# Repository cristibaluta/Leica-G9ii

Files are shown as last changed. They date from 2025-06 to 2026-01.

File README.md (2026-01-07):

# Leica G9II

> The internals of a Panasonic Lumix G9II inside a Leica M-style body — featuring custom CNC-machined parts and redesigned flex cables and buttons.

---

## 📸 Overview

This project is an attempt to make a beautiful small camera from a Lumix G9II body. The camera is focused on street photography and has missing buttons and features.

If you are an expert in any relevant field and see mistakes you are welcome to open issues for discussion, my only qualification to do this is that I was into electronics a long time ago.

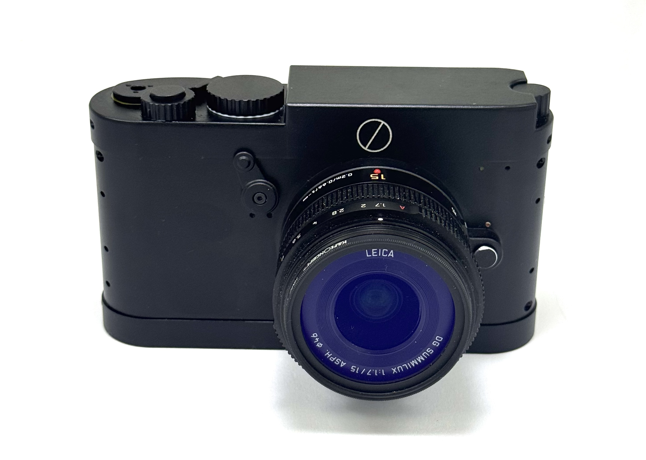
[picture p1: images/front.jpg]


---

## What's Included

- `/CADs/` – STEP files for CNC machining, including threads sheets
- `/FPCBs/` – Schematics and gerber files for the flex cables
- `/Datasheets/` – Some datasheets from used components
- `/BOM/` – List of extra items and purchase links

---

## Materials (BOM)

| Part | Description | Notes |
|---|---|---|
| Top plate | Milled aluminum | Included in CADs |
| Base plate | Milled aluminum |  |
| Front | Milled aluminum |  |
| Back | Milled aluminum |  |
| Heatsink | Milled copper |  |
| Flex cable | Internal routing rework | Included in FPCBs |
| Screws | M1.6 and M2 | Refer to threads sheets in CADs |
| Body (G9II) | Donor camera ||

---

## Build Instructions

> ⚠️ Advanced DIY skills required: electronics, soldering, disassembly without breaking, modifying original parts
> ⚠️ WIP

1. Disassemble Lumix G9II (see [https://www.youtube.com/@CameraSurgery])
2. Machine or print parts from `/CADs/`
3. Print flex cables from `/FPCBs/`
4. Install mount, lens release button
5. Install shutter
6. Install sensor
7. Install front lever and battery flex cable
8. Install heatsink
9. Install mainboard
10. Install top plate dials and flex cables
11. Install back buttons and flex cable
12. Install screen
13. Install viewfinder
14. Install wifi module
15. Assemble
16. Add leatherete
17. Install front lever

---

## Parts removed

1. Lens release push detector (not sure what it was doing beside displaying some info on the screen). There is not enough space to add this push detector
2. The following buttons: ISO-WB, front custom buttons

---

## TO DO:
- The dials are too lose
- The buttons are too short
- Thread missing from the lever clicker
- Remove back wheel
- Dials gaskets too thin (0.5mm), must be wider (1mm)
- Front and back could be extended up and down for better strength

---

## Licence

This project is licensed under the CERN Open Hardware Licence Version 2 – Permissive (CERN-OHL-P-2.0).

---

## 💬 Credits

Created by [Cristian Baluta]  
Youtube: [https://www.youtube.com/@CameraSurgery]

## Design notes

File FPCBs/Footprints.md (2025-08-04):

# Footprints

> 

- HTK AXA573062P https://4donline.ihs.com/images/VipMasterIC/IC/HOND/HOND-S-A0017916280/HOND-S-A0017916306-1.pdf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

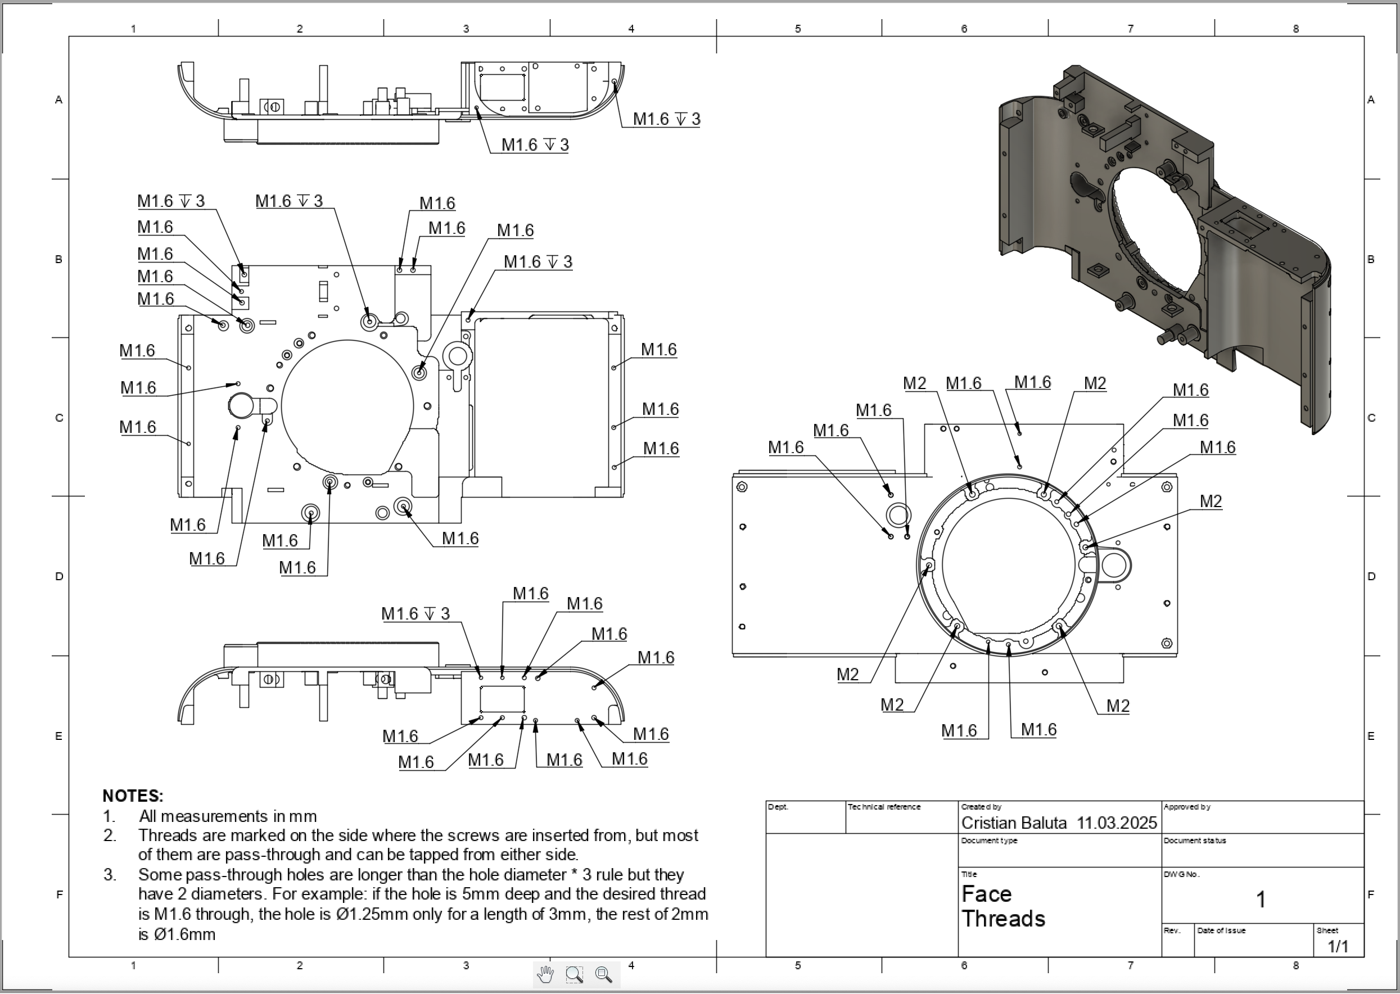
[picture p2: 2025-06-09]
CADs/Face-Threads.png

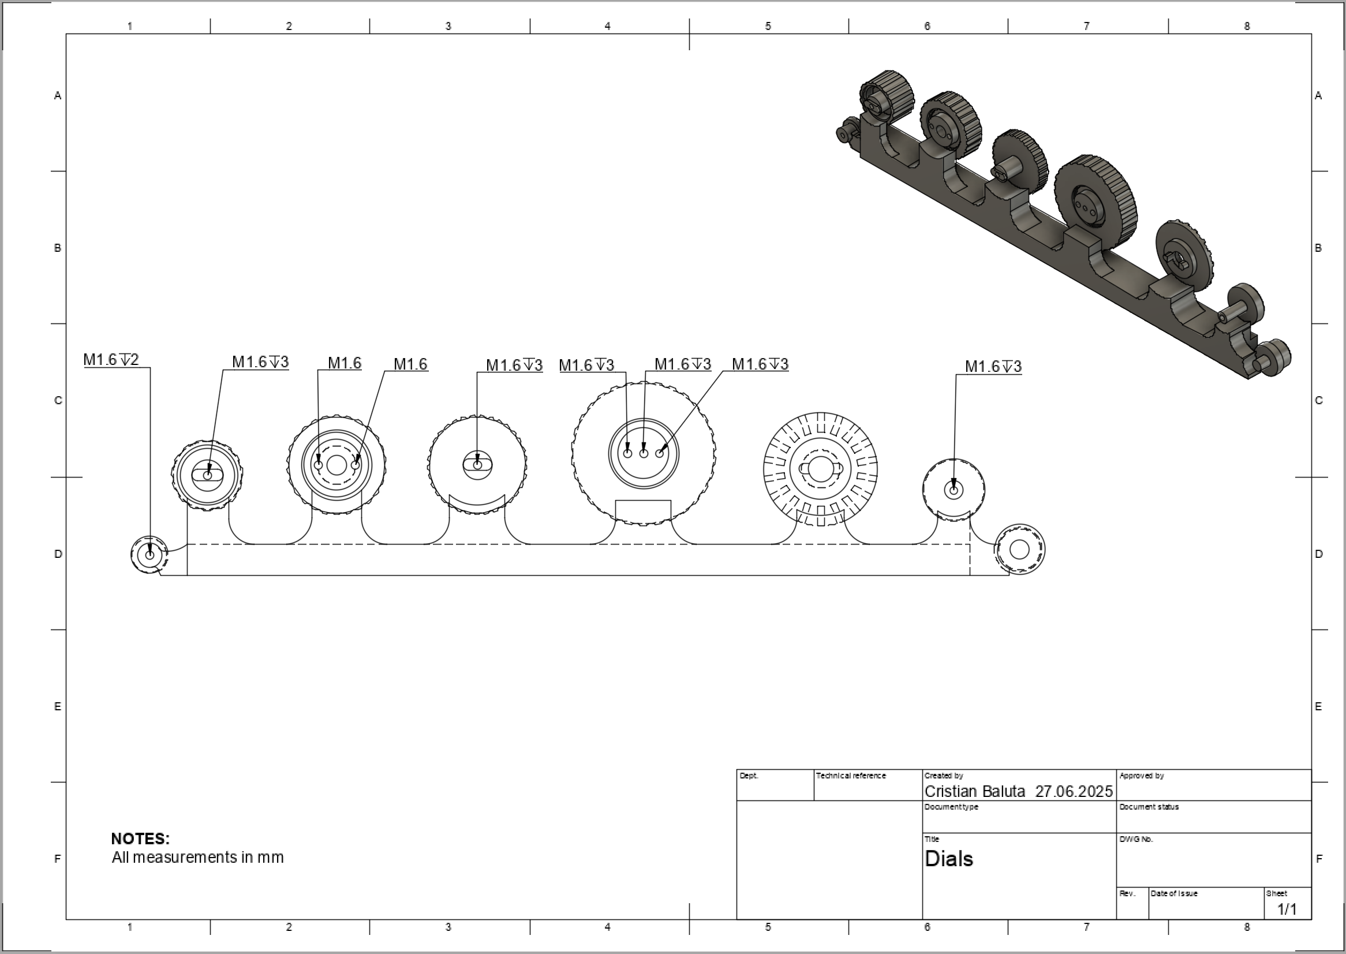
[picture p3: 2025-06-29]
CADs/Dials/Dials-Threads.png

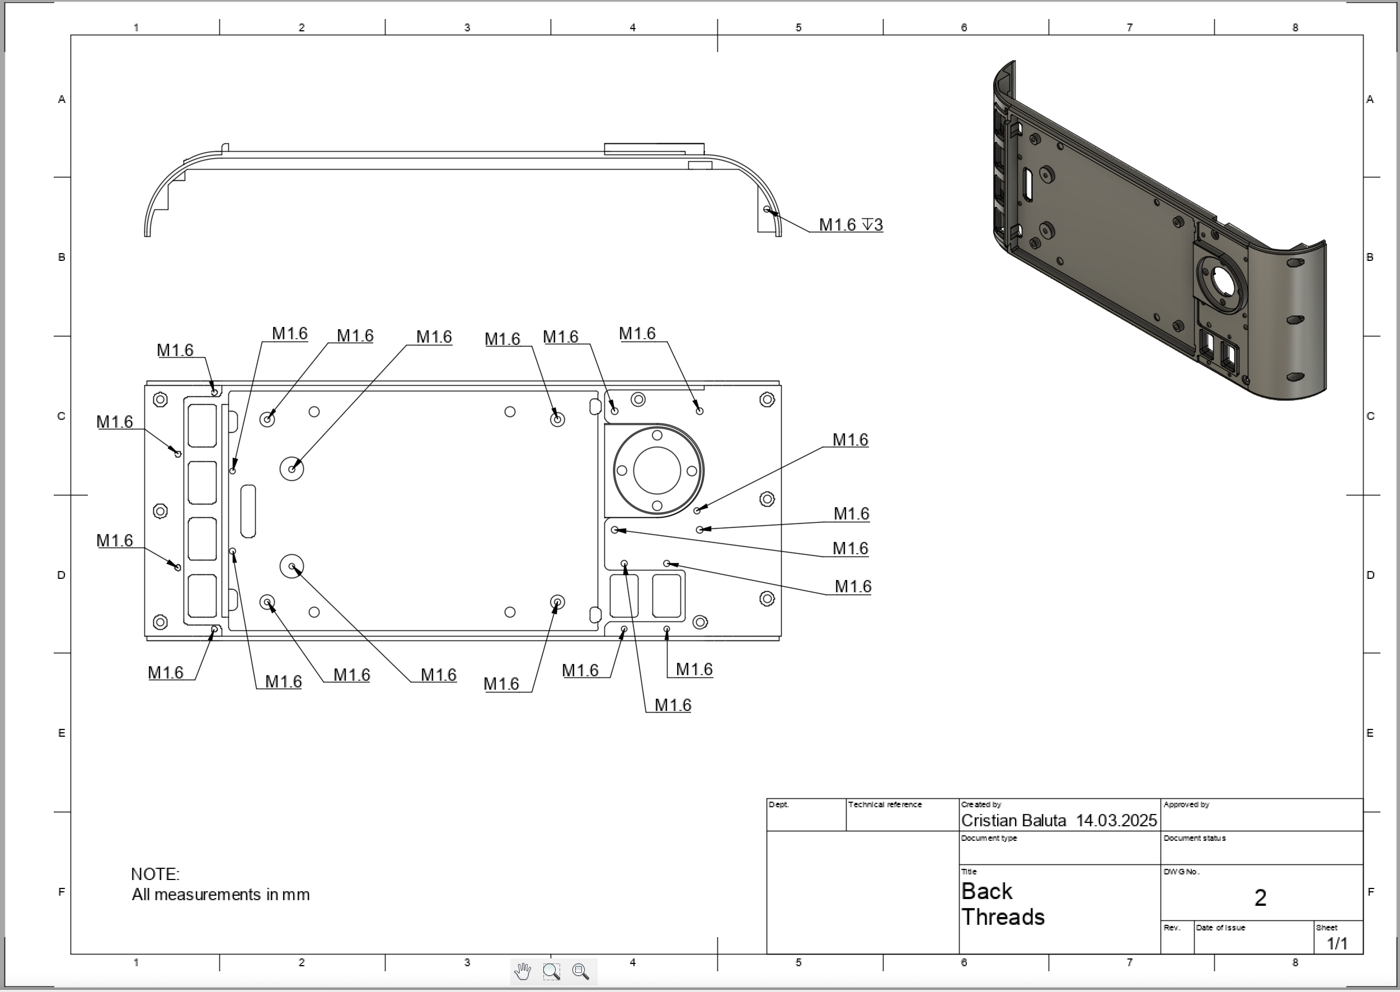
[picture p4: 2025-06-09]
CADs/Back-Threads.png

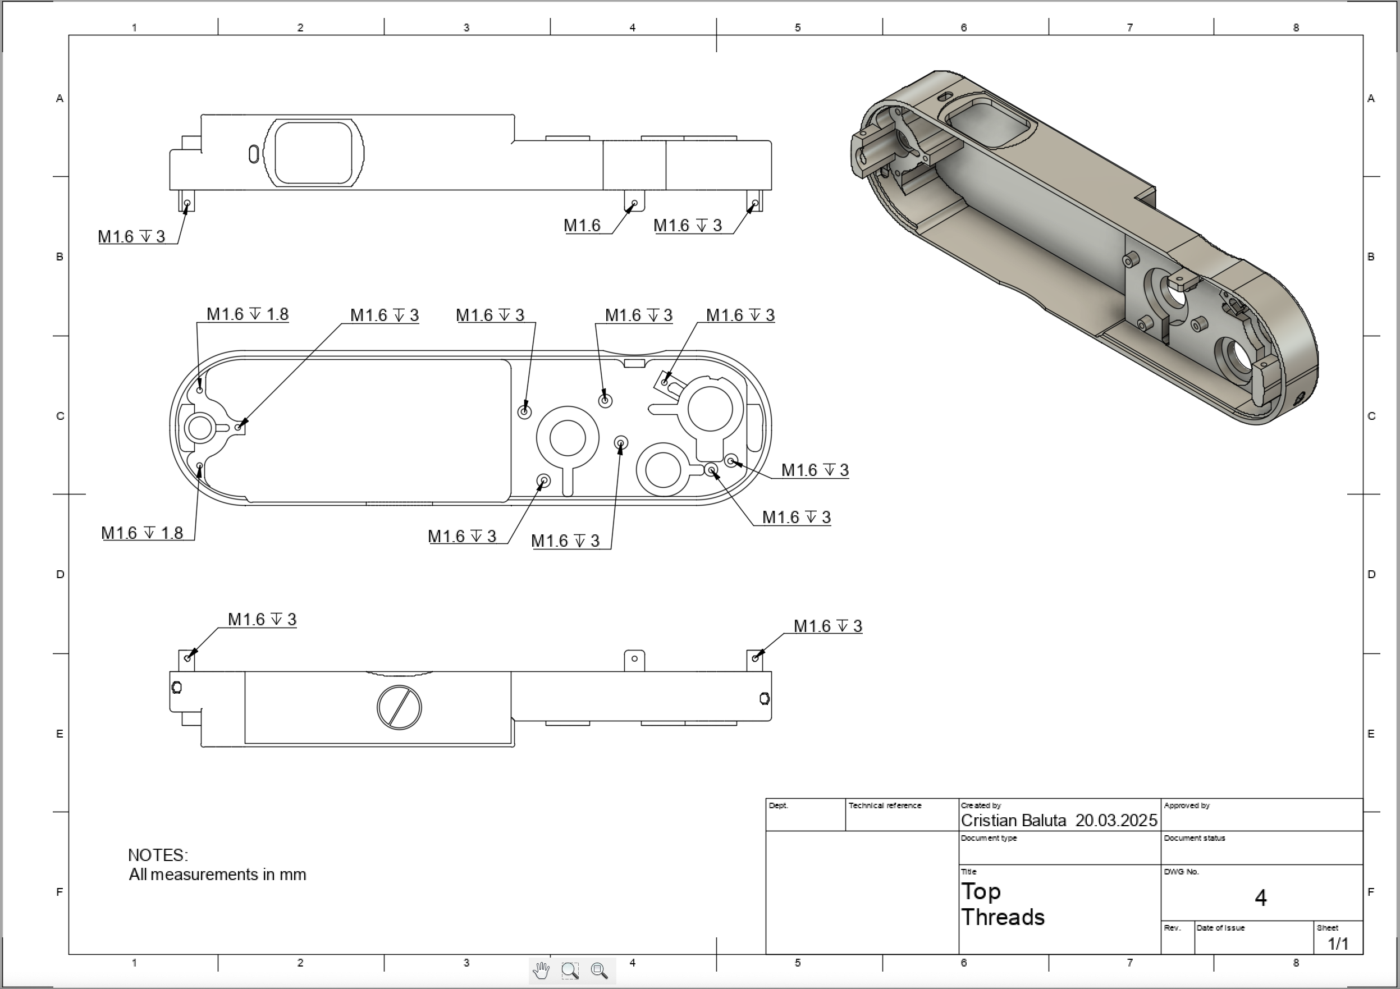
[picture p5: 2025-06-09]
CADs/Top-Threads.png

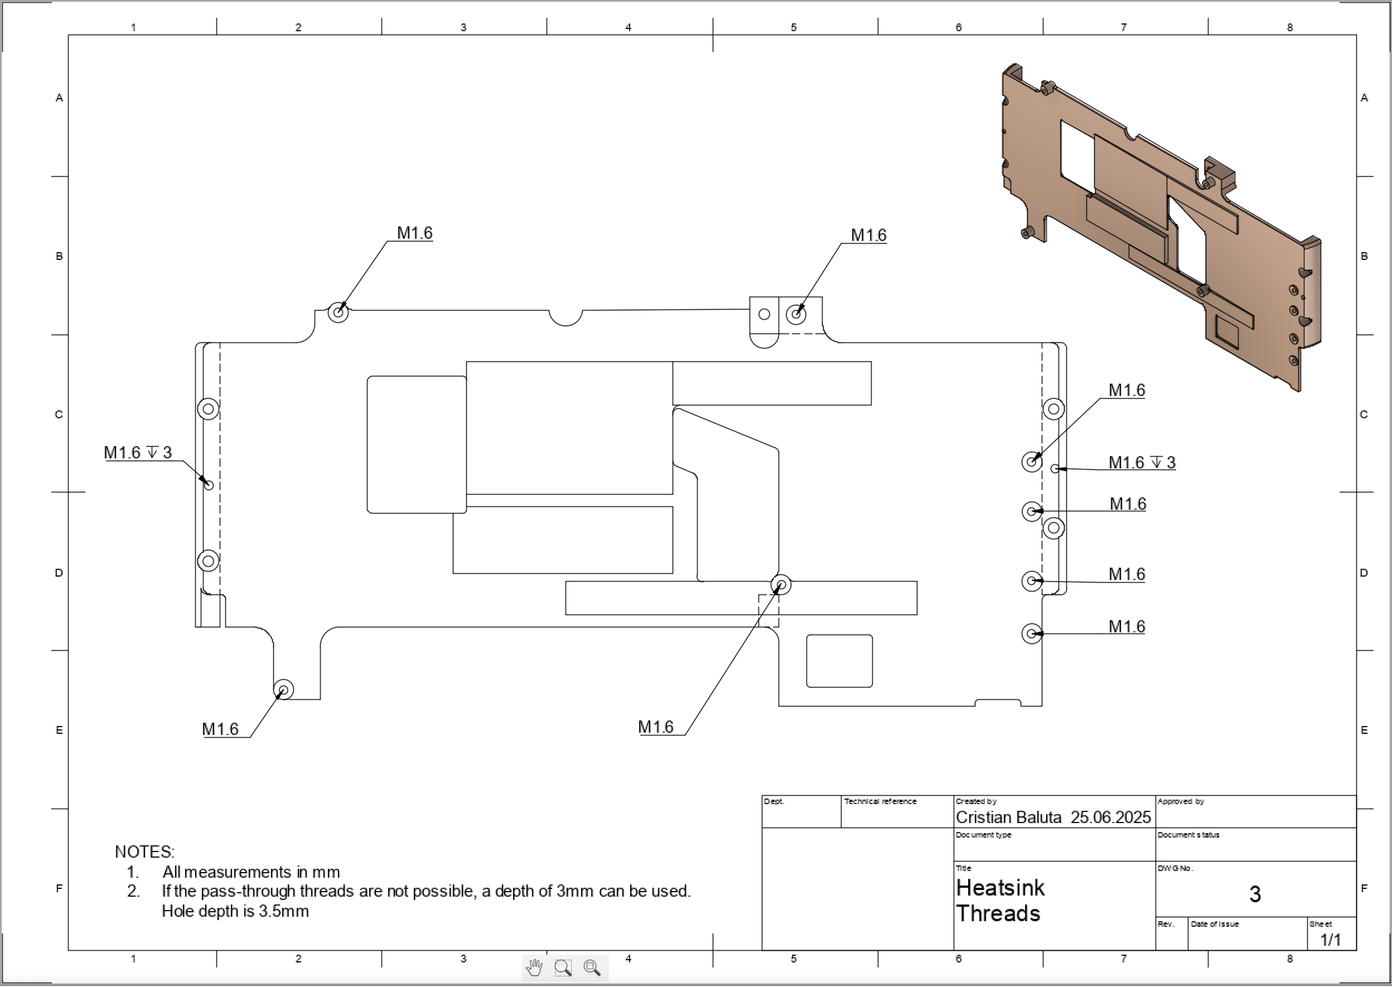
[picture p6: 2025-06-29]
CADs/Heatsink-Threads.png

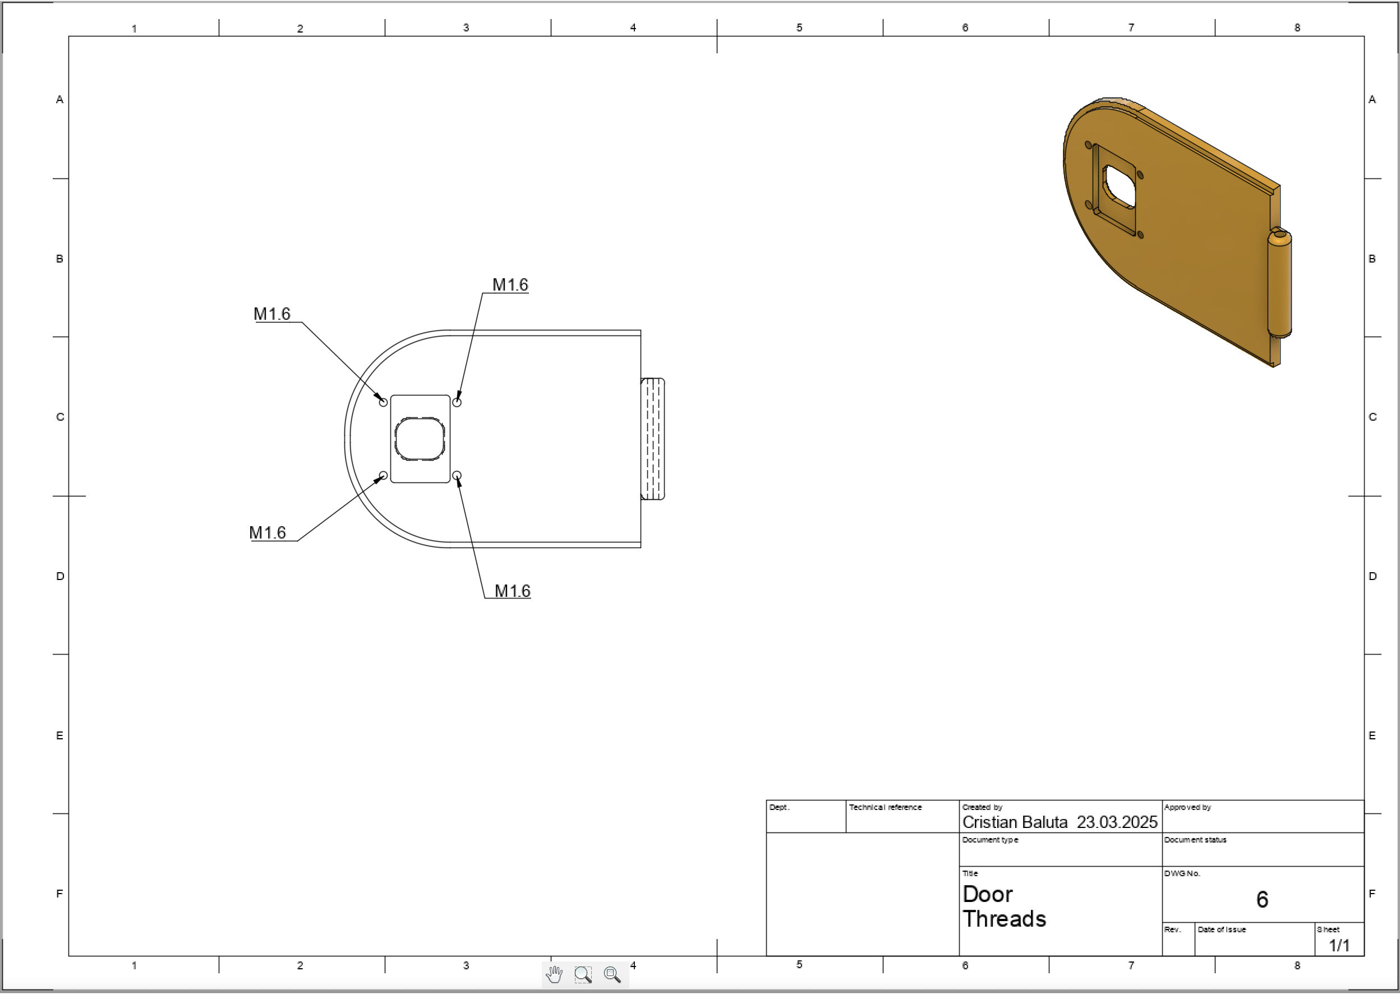
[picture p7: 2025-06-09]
CADs/Door-Threads.png

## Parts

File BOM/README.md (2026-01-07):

# BOM

## Screws

- M1.6 for closing the case. Effective diameter of this screws are 1.57mm, be careful some are poorer quality and smaller diameter. https://www.aliexpress.com/item/4001248931159.html
- M2 for the front lever

## Components

- 0603 resistors replacing the original which were too tiny https://www.aliexpress.com/item/1005008650089395.html
- FPC 61 pins, 2 rows, 0.2 pitch for the EVF extender https://www.aliexpress.com/item/1005001817777187.html
- Canon shutter release button https://www.aliexpress.com/item/1005007803697458.html
- Olympus shutter release button for the second shutter

## Miscellaneous

- Grease https://www.aliexpress.com/item/1005006057635782.html

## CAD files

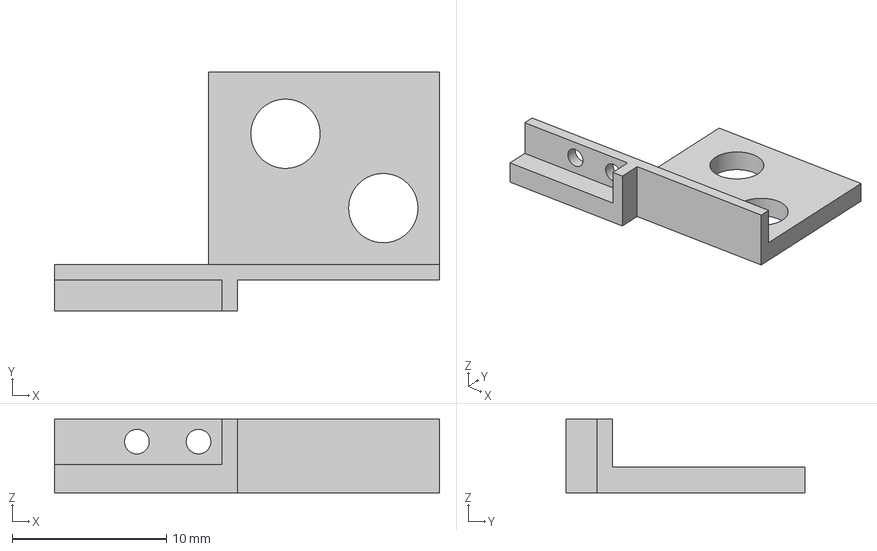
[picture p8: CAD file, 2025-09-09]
CADs/Dials/Gyro.step
25.0 x 15.5 x 4.80 mm

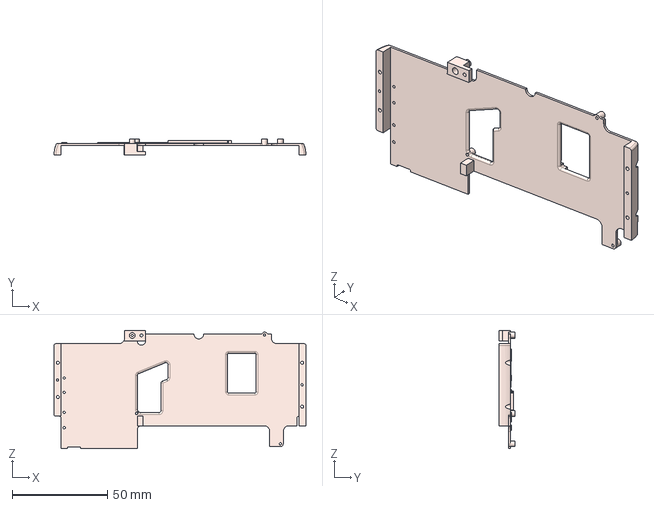
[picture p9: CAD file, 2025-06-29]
CADs/Heatsink.step
132.0 x 8.50 x 62.0 mm

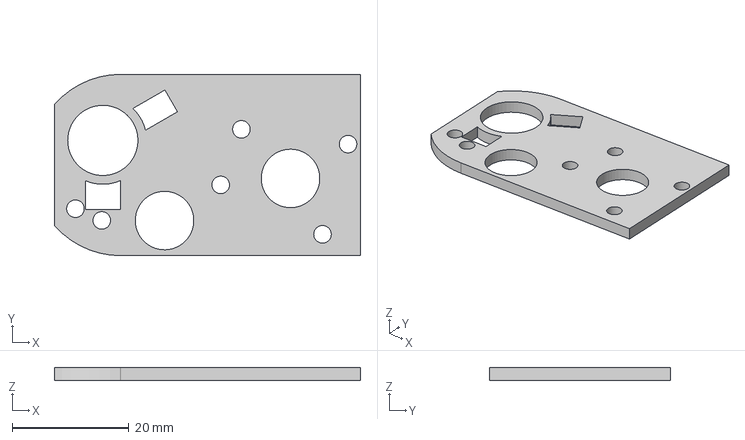
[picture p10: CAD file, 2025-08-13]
CADs/Dials/Mask.step
52.3 x 31.0 x 2.30 mm

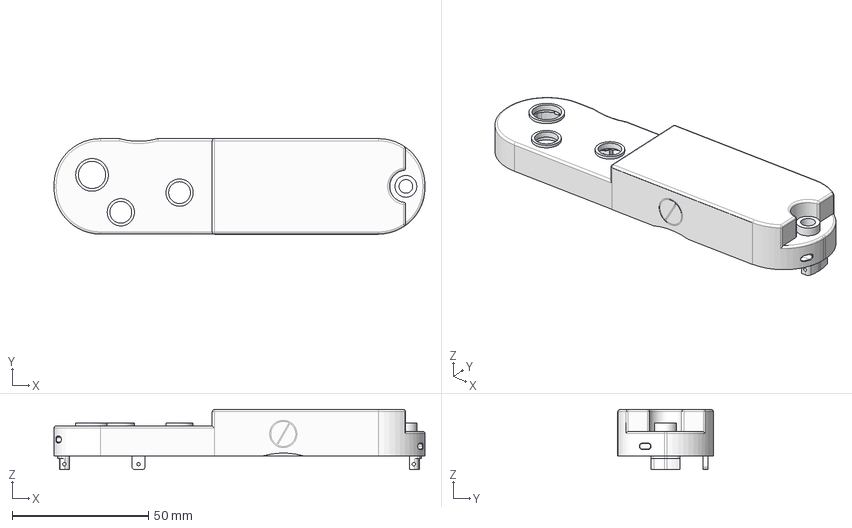
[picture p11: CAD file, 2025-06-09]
CADs/Top.step
136.0 x 35.1 x 22.0 mm

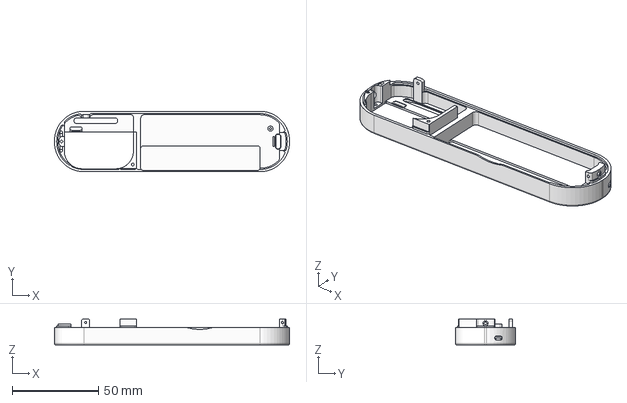
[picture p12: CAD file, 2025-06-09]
CADs/Base Plate.step
136.0 x 35.0 x 15.0 mm

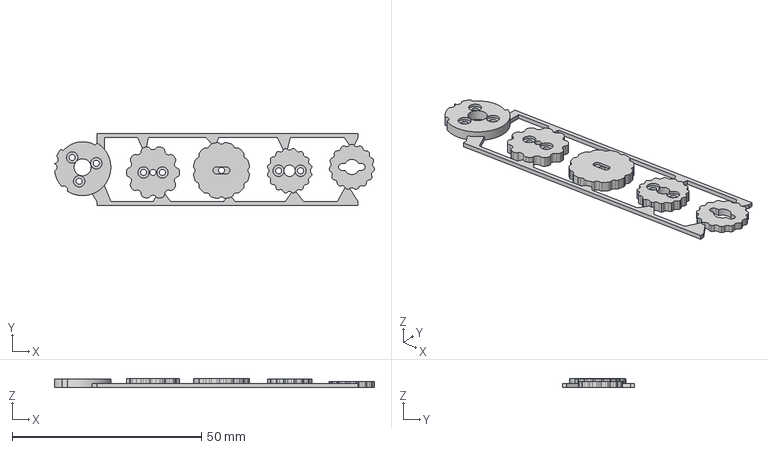
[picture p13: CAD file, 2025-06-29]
CADs/Dials/Clickers-connected.step
84.5 x 19.1 x 2.30 mm

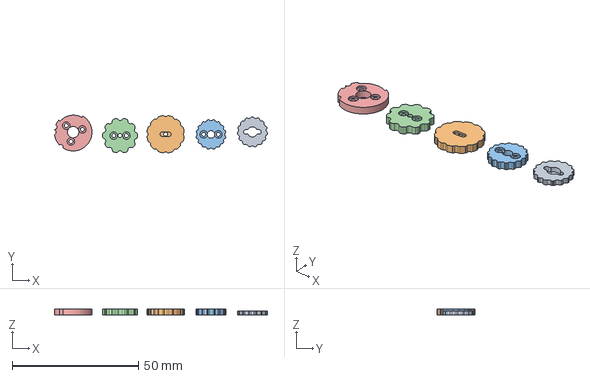
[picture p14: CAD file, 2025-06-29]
CADs/Dials/Clickers-separated.step
84.5 x 15.0 x 2.30 mm

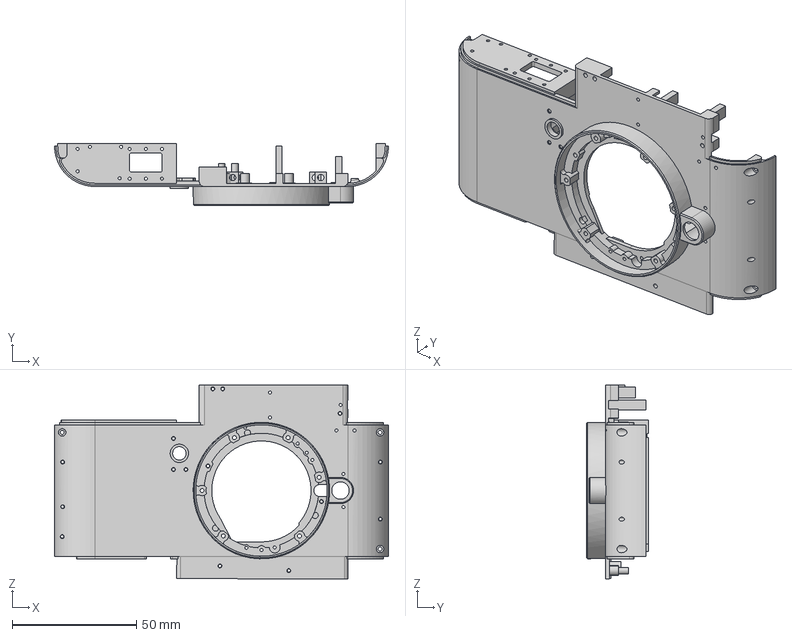
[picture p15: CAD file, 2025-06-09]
CADs/Face.step
134.6 x 24.9 x 78.0 mm

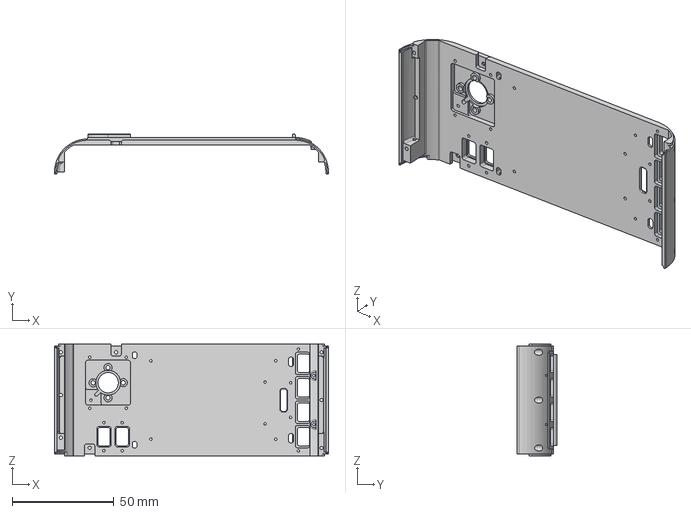
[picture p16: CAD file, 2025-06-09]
CADs/Back.step
134.6 x 19.8 x 55.0 mm

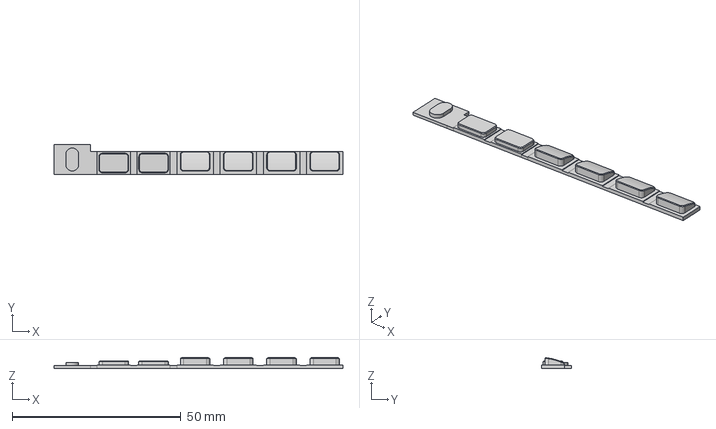
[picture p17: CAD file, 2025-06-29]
CADs/Dials/Back Buttons.step
85.6 x 8.88 x 3.17 mm

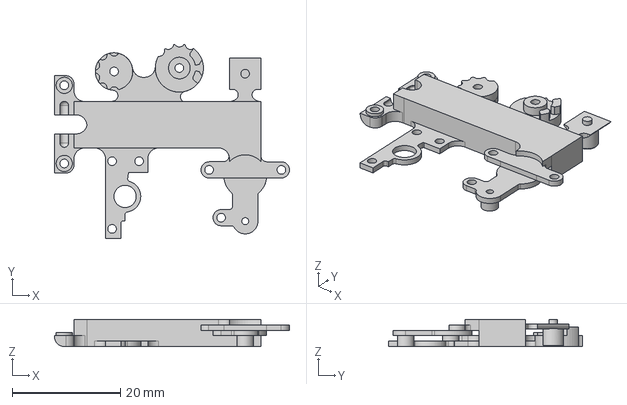
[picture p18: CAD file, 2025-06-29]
CADs/Dials/Miscellaneous.step
43.4 x 35.9 x 5.00 mm

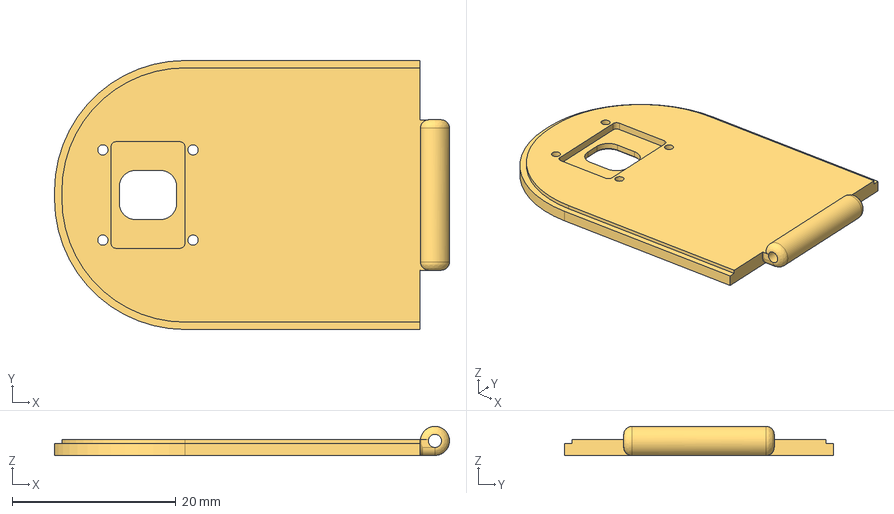
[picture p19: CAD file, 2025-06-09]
CADs/Door.step
48.2 x 32.8 x 3.58 mm

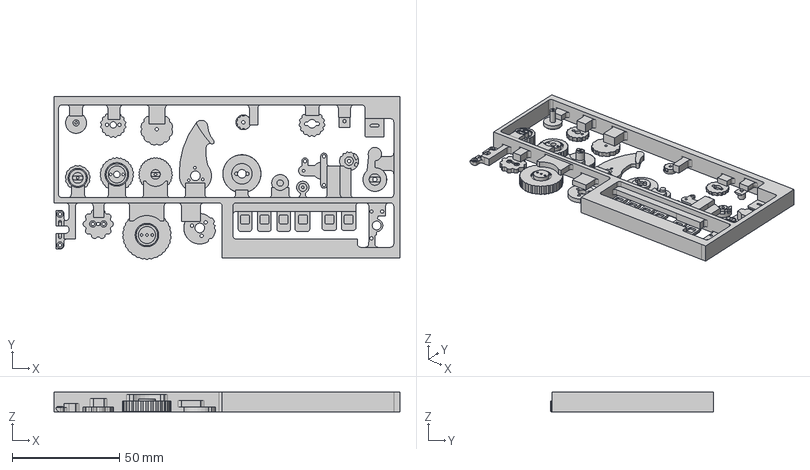
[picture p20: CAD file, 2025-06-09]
CADs/Buttons.step
161.1 x 75.7 x 9.20 mm

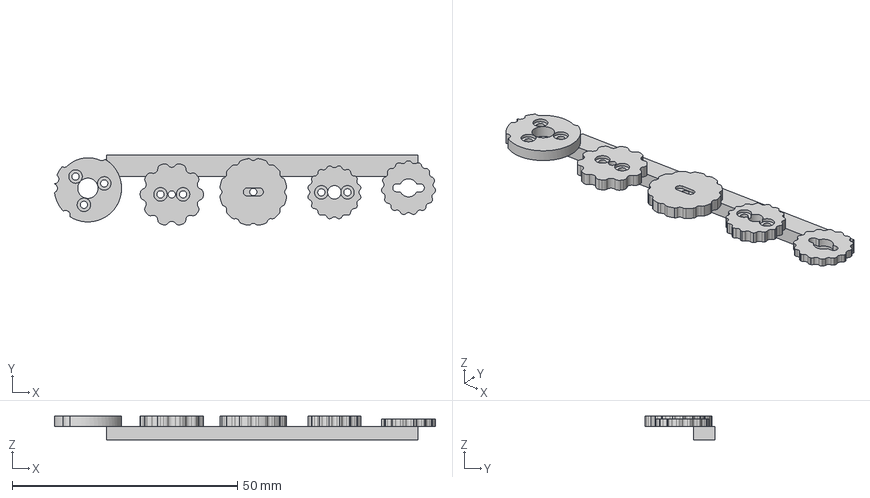
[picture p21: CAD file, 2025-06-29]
CADs/Dials/Clickers.step
84.5 x 15.6 x 5.30 mm

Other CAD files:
Engravings/TopPlate.dxf
CADs/Dials/Dials.step
CADs/Dials/Levers.step
CADs/Dials/ModeDial.step

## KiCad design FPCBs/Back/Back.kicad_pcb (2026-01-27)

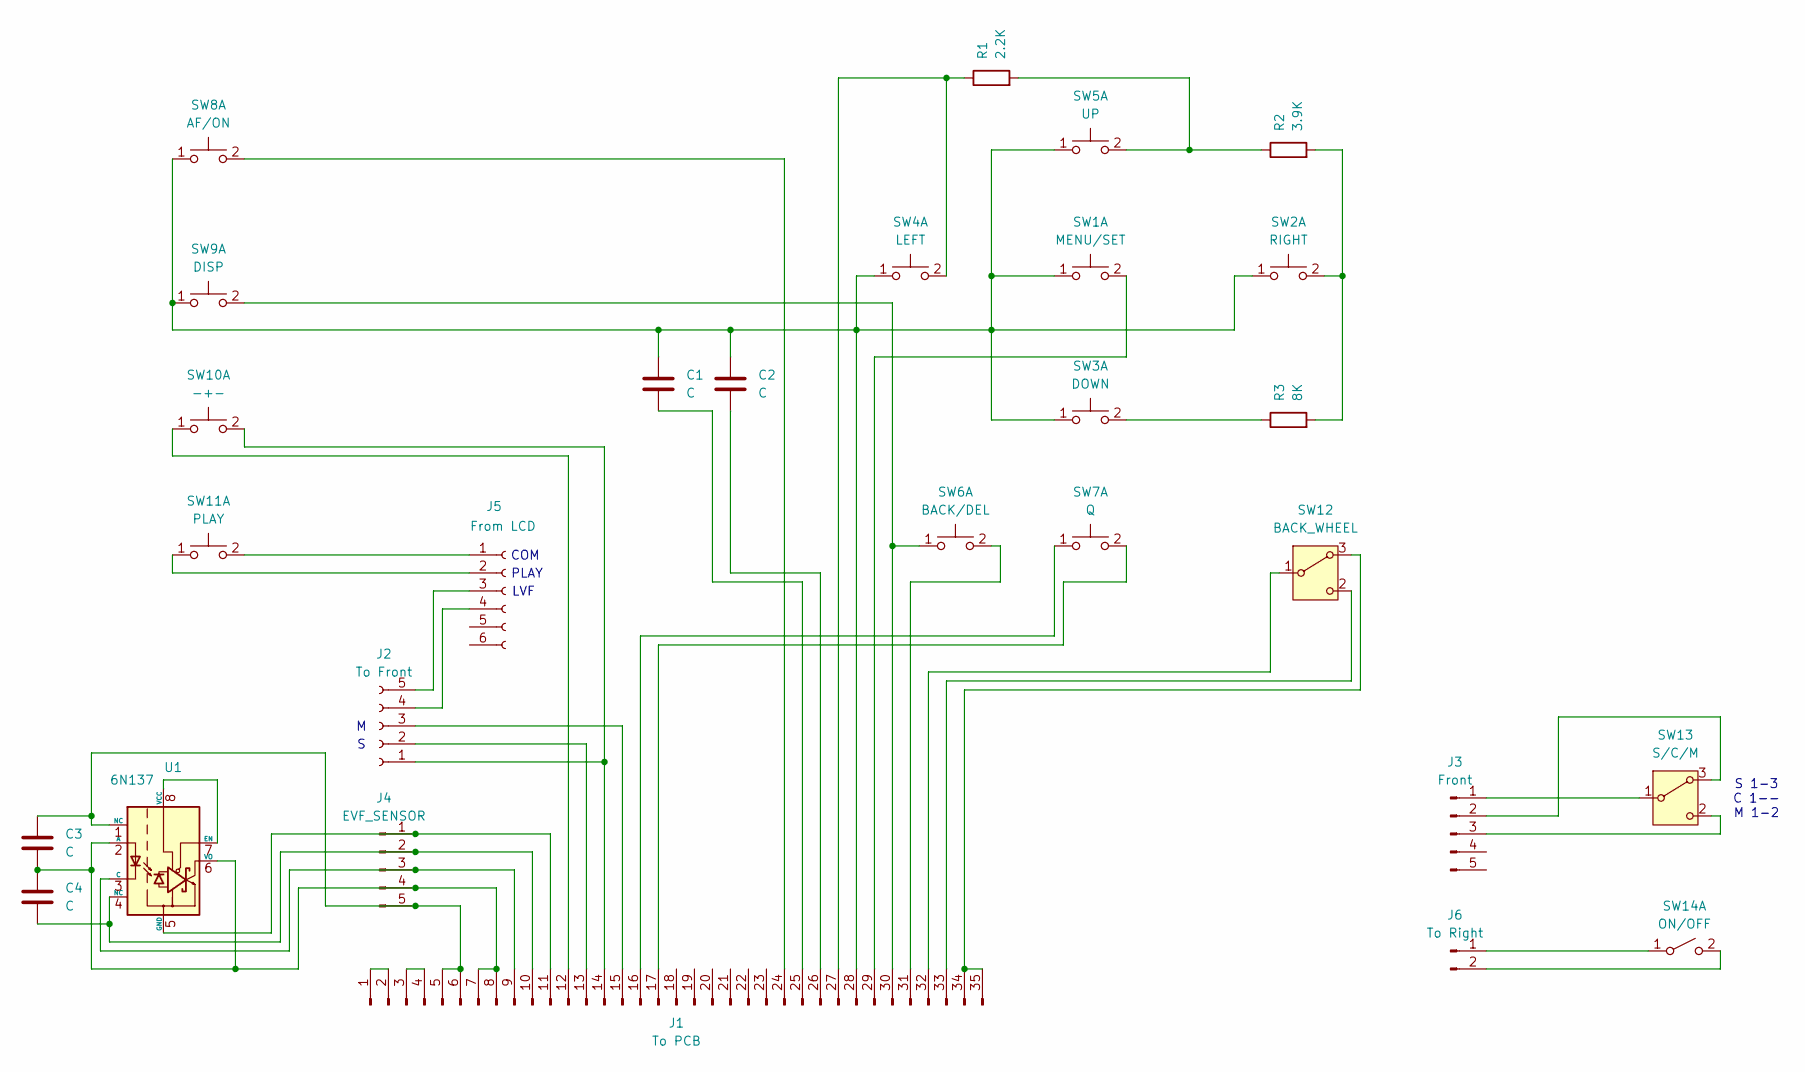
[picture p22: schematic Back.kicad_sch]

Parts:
C1, C2, C3, C4: C; R_0603
J1: To PCB; FPC-2Rows-35Pins-0.5mm
J2: To Front; Connector-1Row-5Pins-0.40mm
J3: Front; FPC-1Row-5Pins-0.40mm
J4: EVF_SENSOR; FPC-1Row-7Pins-0.40mm
J5: From LCD; Connector-1Row-6Pins-0.40mm
J6: To Right; Connector-Screw-2Pins
R1: 2.2K; R_0603
R2: 3.9K; R_0603
R3: 8K; R_0603
SW1: MENU/SET; Push_Button
SW2: RIGHT; Push_Button
SW3: DOWN; Push_Button
SW4: LEFT; Push_Button
SW5: UP; Push_Button
SW6: BACK/DEL; Push_Button
SW7: Q; Push_Button
SW8: AF/ON; Push_Button
SW9: DISP; Push_Button
SW10: -+-; Push_Button
SW11: PLAY; Push_Button
SW12: BACK_WHEEL; back_dial
SW13: S/C/M; Switch_Detection_Bidirectional
SW14: ON/OFF; Switch_Detection
U1: 6N137; Optocoupler_EVF

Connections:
unnamed: J1.1, J1.2
unnamed: J1.3, J1.4
unnamed: C3.1, J1.5, J1.6, J4.5, U1.1 (NC)
unnamed: C3.2, C4.1, J1.7, J1.8, J4.4, U1.2 (A), U1.6 (VO)
unnamed: J1.9, J4.3, U1.3 (C)
unnamed: C4.2, J1.10, J4.2, U1.4 (NC)
unnamed: J1.11, J4.1, U1.5 (GND)
unnamed: J1.12, SW10.1 (C)
unnamed: J1.13, J2.2
unnamed: J1.14, J2.1, SW10.2 (D)
unnamed: J1.15, J2.3
unnamed: J1.16, SW7.1 (C)
unnamed: J1.17, SW7.2 (D)
unnamed: J1.24, SW8.2 (D)
unnamed: C1.2, J1.25
unnamed: C2.2, J1.26
unnamed: J1.27, R1.1, SW4.2 (D)
unnamed: C1.1, C2.1, J1.28, SW1.1 (C), SW2.1 (C), SW3.1 (C), SW4.1 (C), SW5.1 (C), SW8.1 (C), SW9.1 (C)
unnamed: J1.29, SW1.2 (D)
unnamed: J1.30, SW6.1 (C), SW9.2 (D)
unnamed: J1.31, SW6.2 (D)
unnamed: J1.32, SW12.1 (B)
unnamed: J1.33, SW12.2 (C)
unnamed: J1.34, J1.35, SW12.3 (A)
unnamed: J2.4, J5.4
unnamed: J2.5, J5.3
unnamed: J3.1, SW13.1 (B)
unnamed: J3.2, SW13.3 (A)
unnamed: J3.3, SW13.2 (C)
unnamed: J5.1, SW11.2 (D)
unnamed: J5.2, SW11.1 (C)
unnamed: J6.1, SW14.1 (A)
unnamed: J6.2, SW14.2 (B)
unnamed: R2.2, R3.2, SW2.2 (D)
unnamed: R3.1, SW3.2 (D)
unnamed: R1.2, R2.1, SW5.2 (D)
unnamed: U1.7 (EN), U1.8 (VCC)

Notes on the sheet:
PLAY
COM
S 1-3 C 1-- M 1-2
LVF

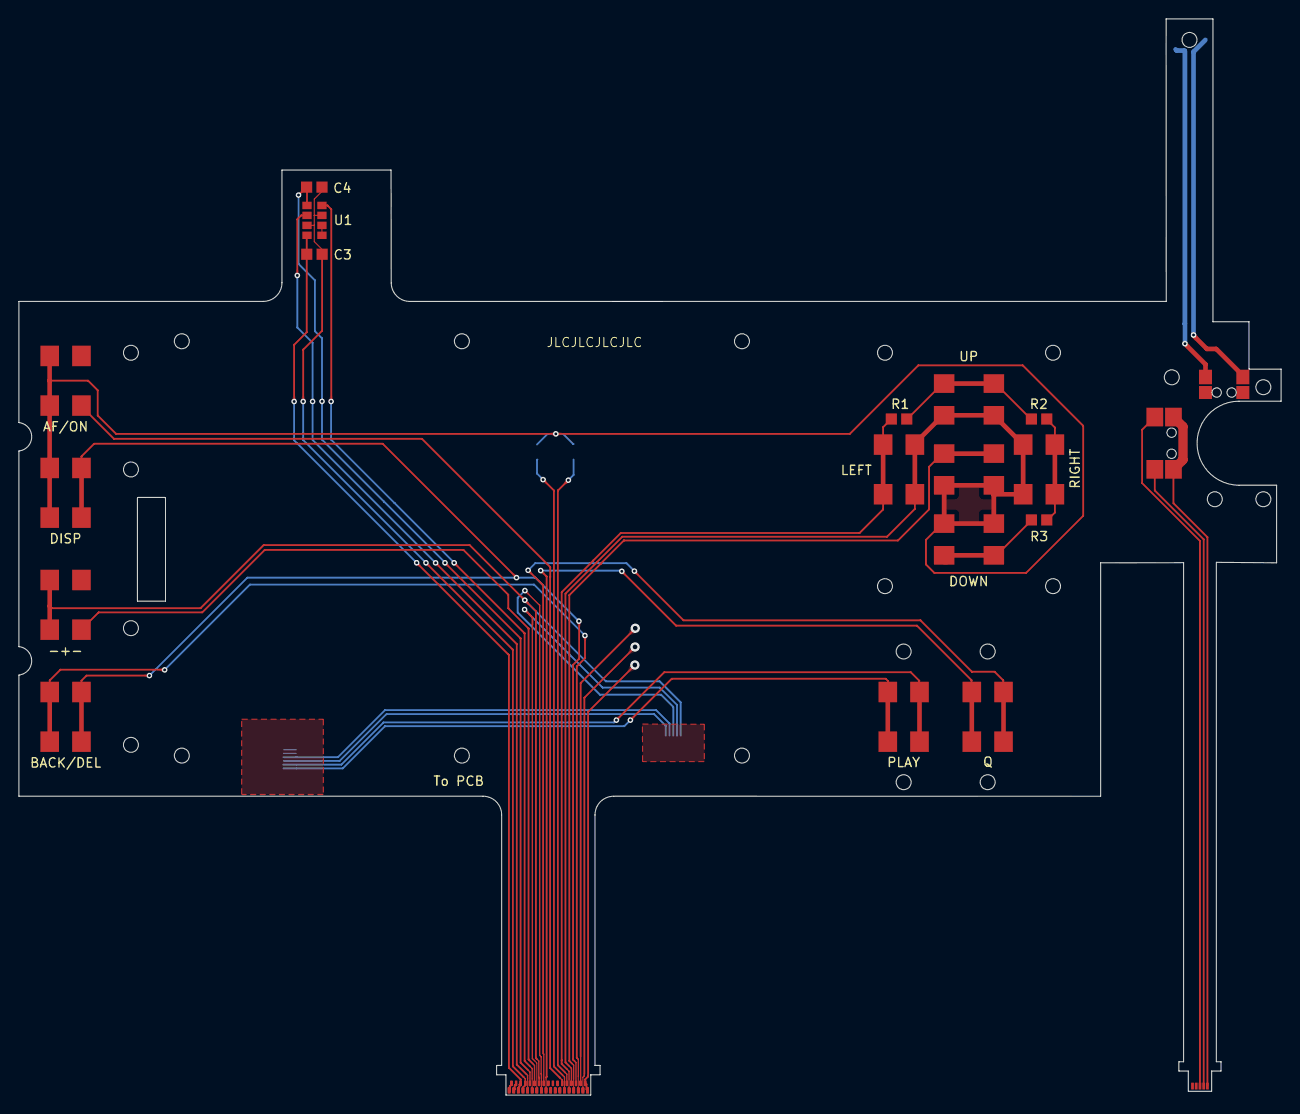
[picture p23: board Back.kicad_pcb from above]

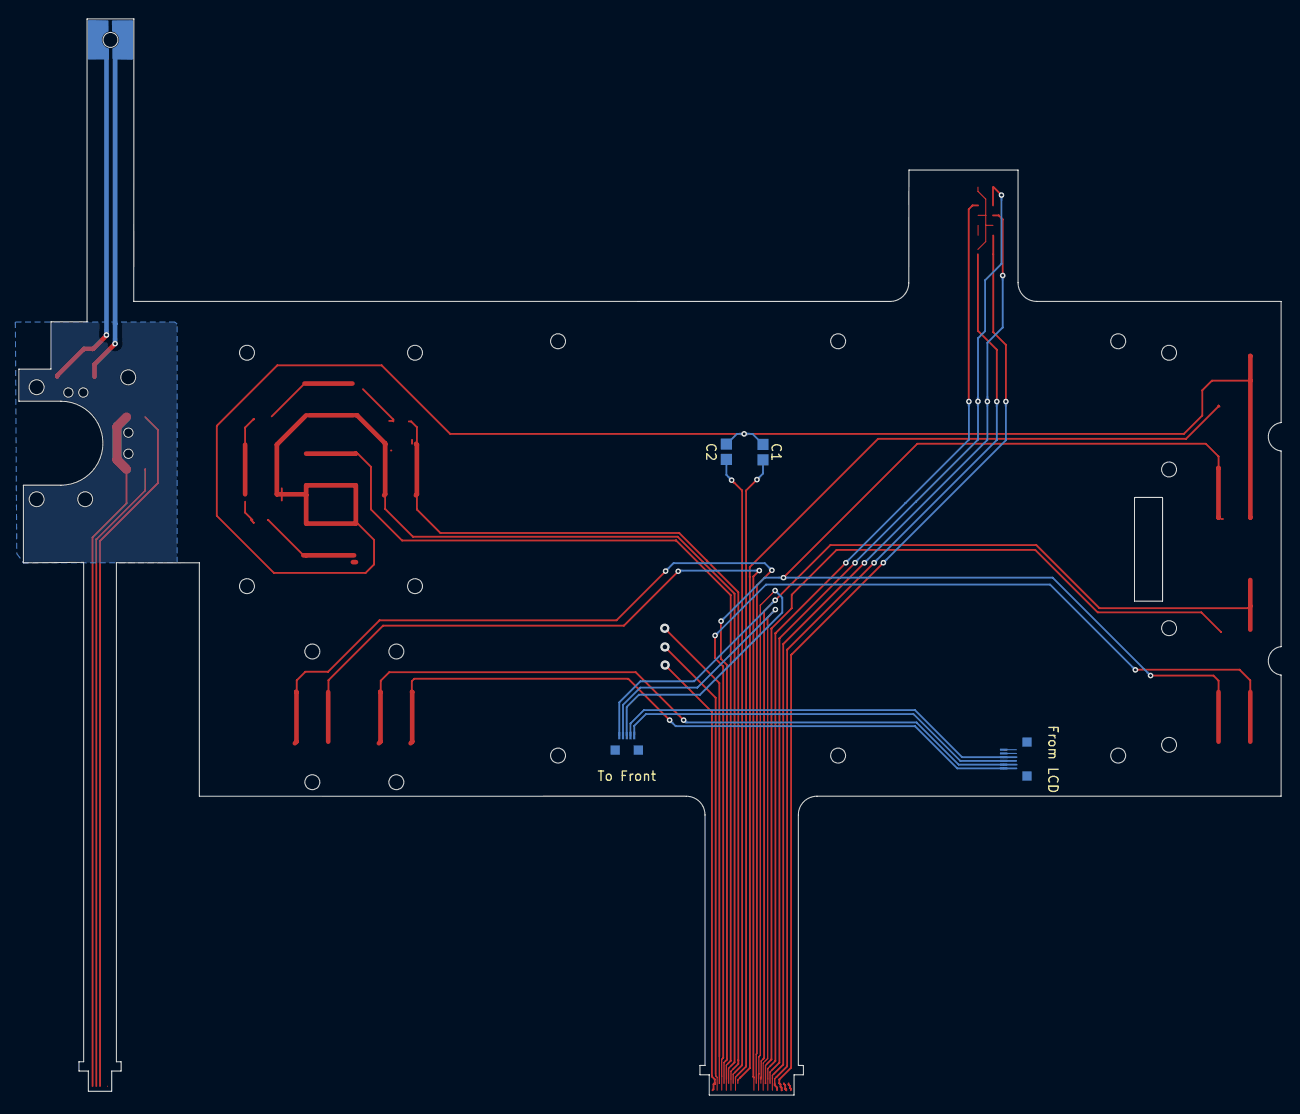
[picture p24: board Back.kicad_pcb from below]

Board: 2 copper layers, 135.2 x 115.3 mm, 26 parts (5 on the bottom side), 35 nets.

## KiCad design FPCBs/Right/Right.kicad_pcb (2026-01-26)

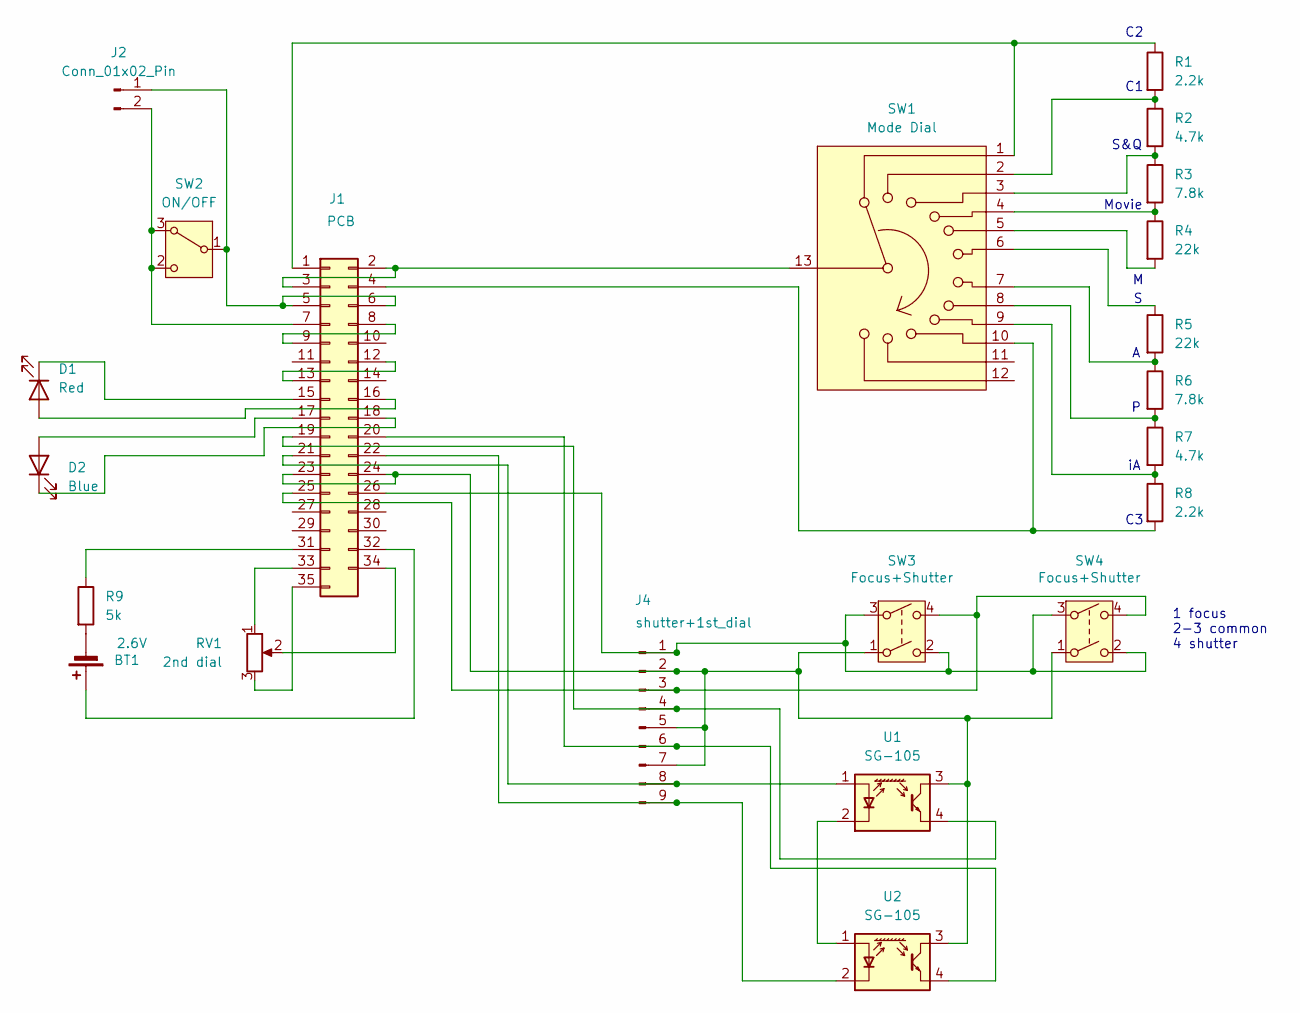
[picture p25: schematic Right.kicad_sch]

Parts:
BT1: 2.6V; Battery_Cell
D1: Red; LED
D2: Blue; LED
J1: PCB; FPC-2Rows-35Pins-0.5mm
J2: Conn_01x02_Pin; Connector-Screw-2Pins
J4: shutter+1st_dial; Connector-2Rows-9Pins-0.60mm
R1, R8: 2.2k; R_0603
R2, R7: 4.7k; R_0603
R3, R6: 7.8k; R_0603
R4, R5: 22k; R_0603
R9: 5k; R_0603
RV1: 2nd dial; 2nd_dial
SW1: Mode Dial; Switch_Modes
SW2: ON/OFF; Switch_ON_OFF
SW3: Focus+Shutter; Shutter_Canon
SW4: Focus+Shutter; Shutter_Olympus
U1, U2: SG-105; Opto_Switch

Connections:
unnamed: BT1.1 (+), J1.32
unnamed: BT1.2 (-), R9.2
unnamed: D1.2 (A), J1.16
unnamed: D1.1 (K), J1.15
unnamed: D2.2 (A), J1.17
unnamed: D2.1 (K), J1.18
unnamed: J1.1, R1.1, SW1.1
unnamed: J1.2, J1.3, SW1.13
unnamed: J1.4, R8.2, SW1.10
unnamed: J1.5, J1.6, J2.1, SW2.1 (B)
unnamed: J1.7, J2.2, SW2.2 (C), SW2.3 (A)
unnamed: J1.8, J1.9
unnamed: J1.12, J1.13
unnamed: J1.19, J4.4, U1.4 (E)
unnamed: J1.20, J4.6, U2.4 (E)
unnamed: J1.21, J4.8, U1.1 (A)
unnamed: J1.22, J4.9, U2.2 (K)
unnamed: J1.23, J1.24, J4.2, J4.5, J4.7, SW3.1, SW4.1, U1.3 (C), U2.3 (C)
unnamed: J1.25, J4.3, SW3.4, SW4.4
unnamed: J1.26, J4.1, SW3.2, SW3.3, SW4.2, SW4.3
unnamed: J1.31, R9.1
unnamed: J1.33, RV1.1
unnamed: J1.34, RV1.2
unnamed: J1.35, RV1.3
unnamed: R1.2, R2.1, SW1.2
unnamed: R2.2, R3.1, SW1.3
unnamed: R3.2, R4.1, SW1.4
unnamed: R4.2, SW1.5
unnamed: R5.1, SW1.6
unnamed: R5.2, R6.1, SW1.7
unnamed: R6.2, R7.1, SW1.8
unnamed: R7.2, R8.1, SW1.9
unnamed: U1.2 (K), U2.1 (A)

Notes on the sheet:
1 focus 2-3 common 4 shutter
S&Q
Movie

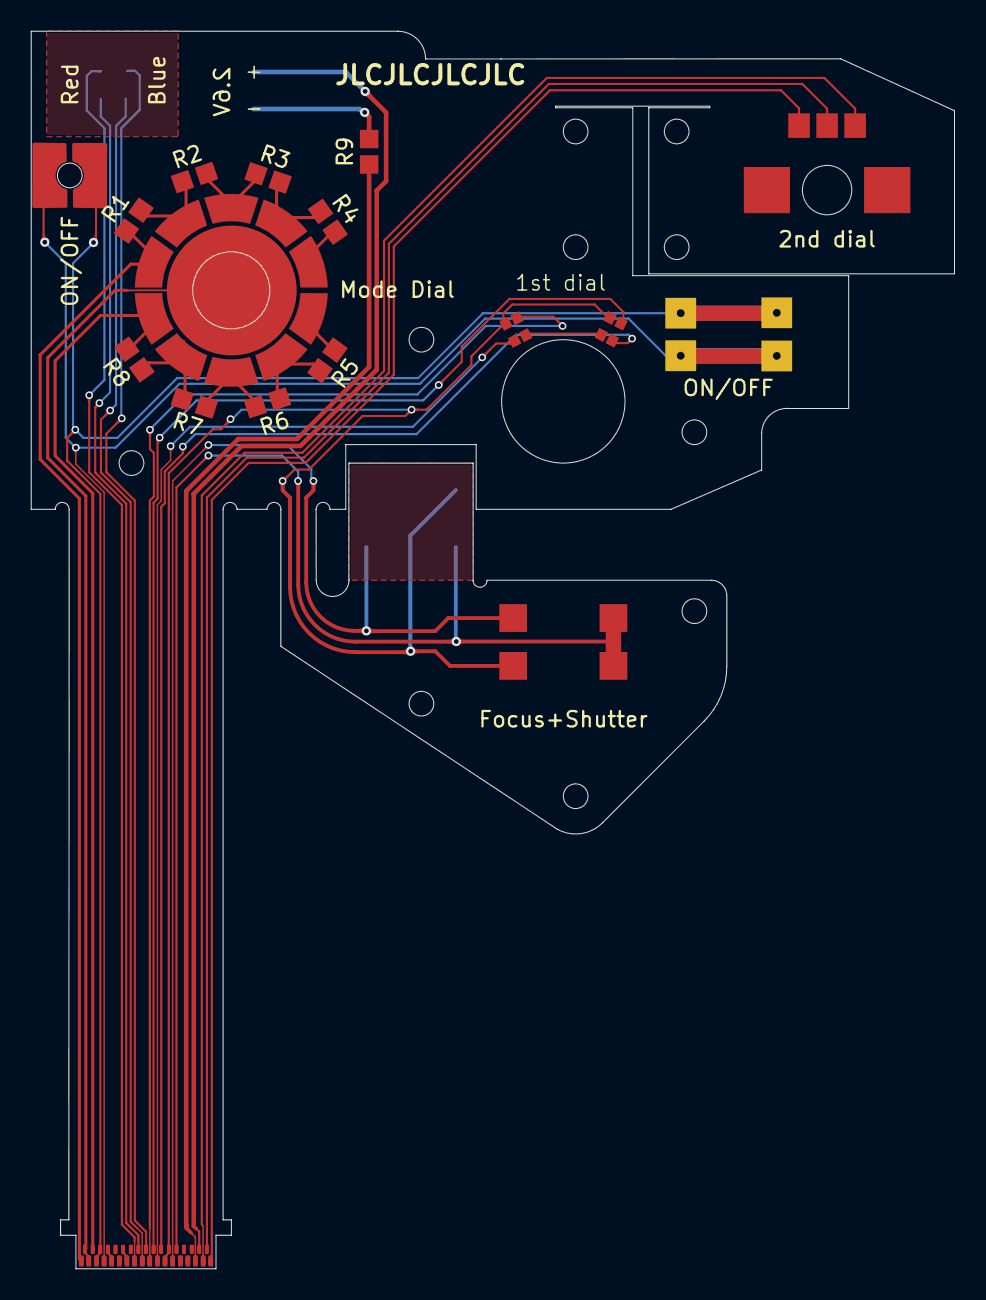
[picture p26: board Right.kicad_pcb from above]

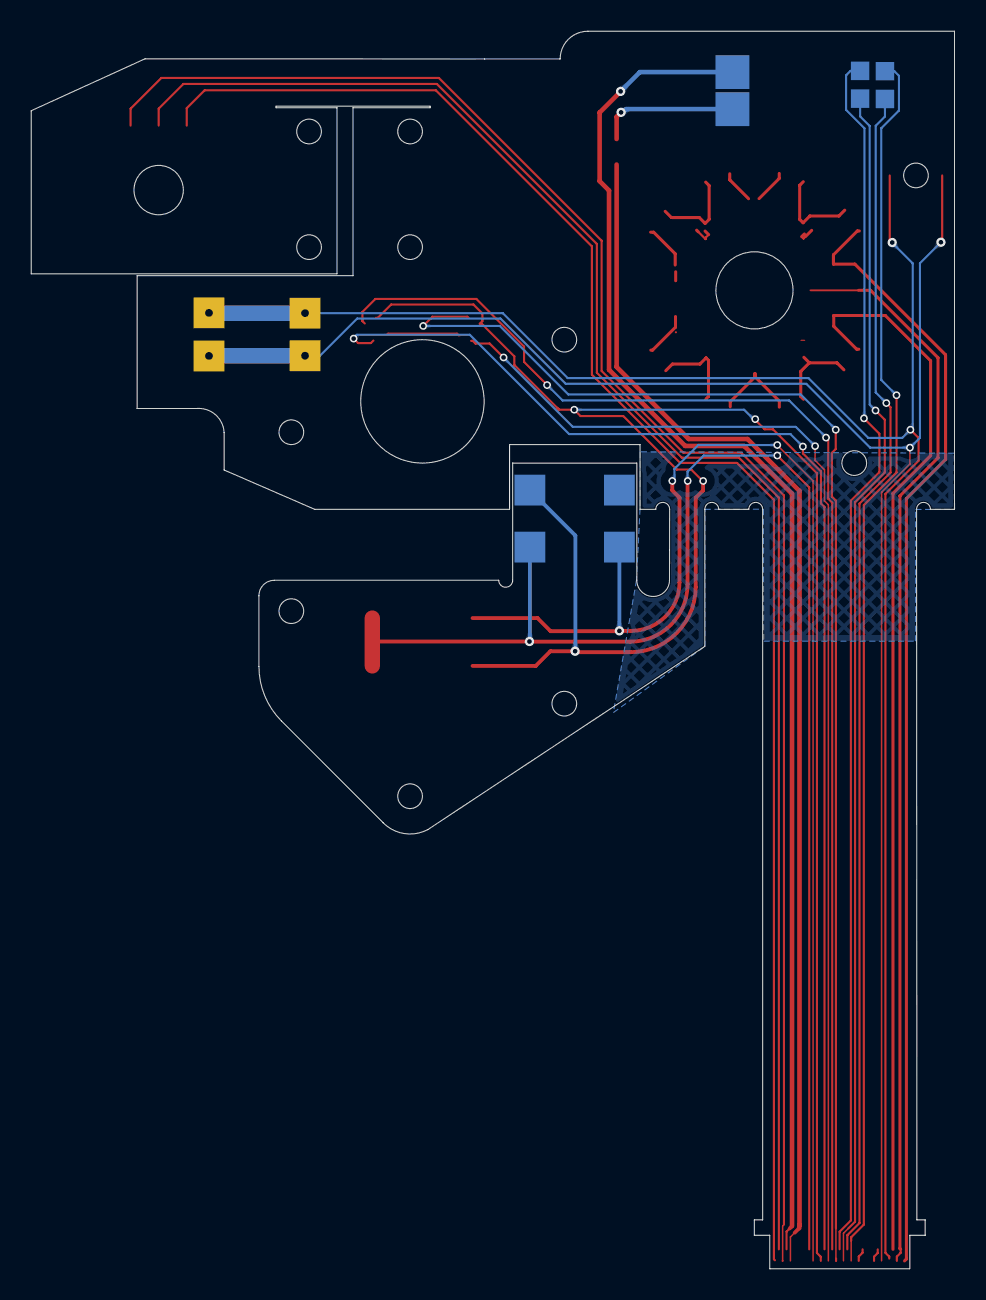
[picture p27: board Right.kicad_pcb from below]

Board: 2 copper layers, 59.9 x 80.2 mm, 21 parts (5 on the bottom side), 33 nets.

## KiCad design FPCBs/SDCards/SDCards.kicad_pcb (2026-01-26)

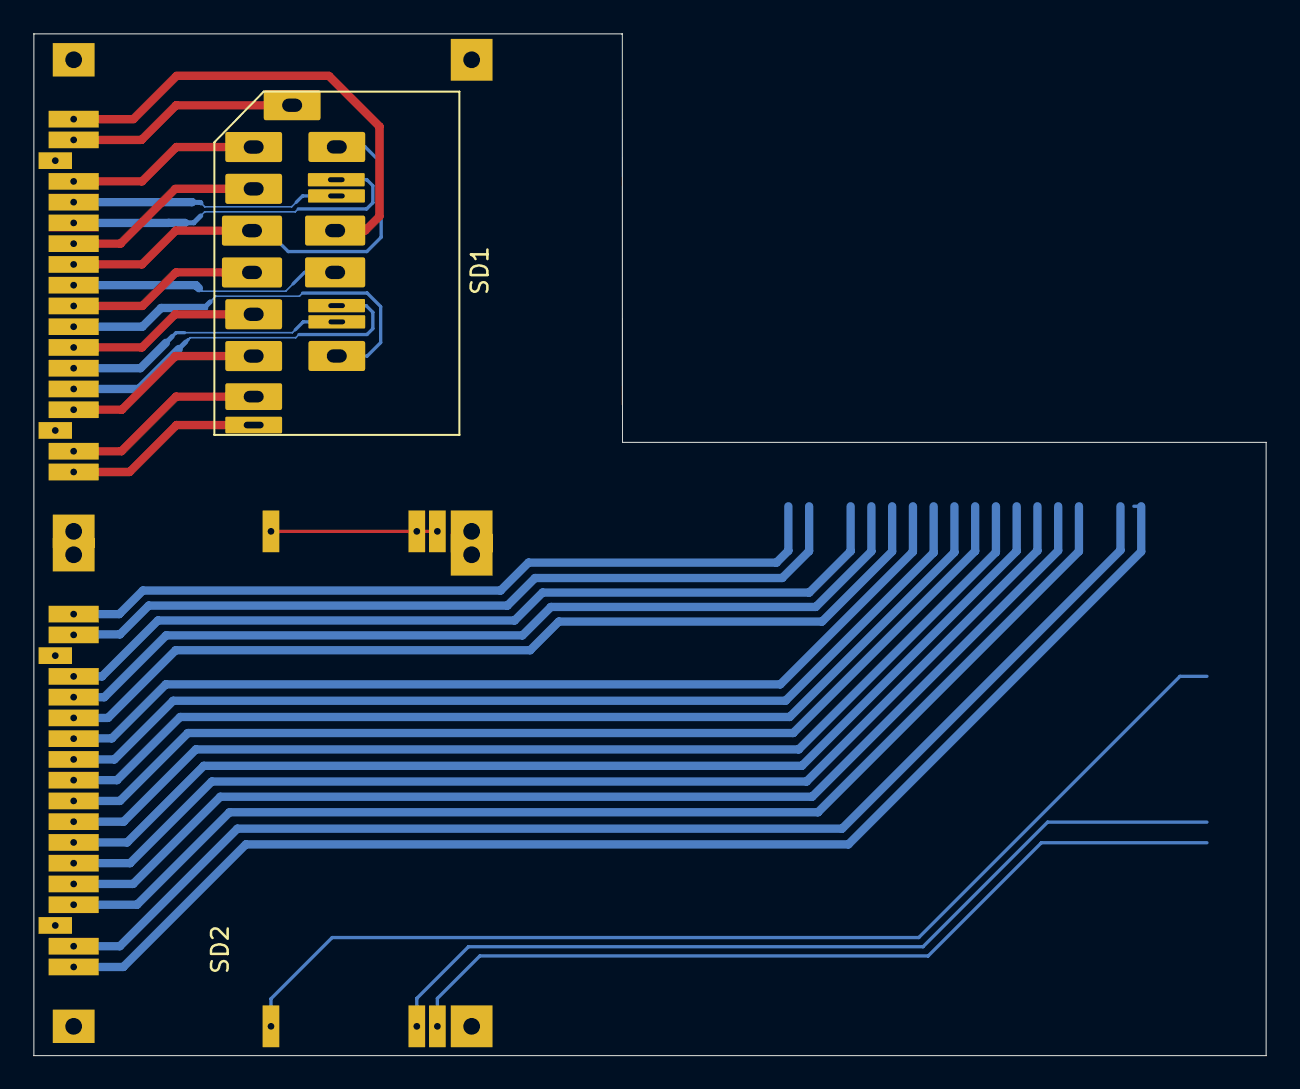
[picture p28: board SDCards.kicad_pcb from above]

Board: 2 copper layers, 73.7 x 61.1 mm, 4 parts (1 on the bottom side), 37 nets.

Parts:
J1: SD1; SD_Card_Socket_UHS-II_Extender
J2: SD1; SD_Card_Chip_UHS-II
J3: SD2; SD_Card_Socket_UHS-II_Extender
J4: SD2; SD_Card_Socket_UHS-II_HTK_AXA573062

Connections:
unnamed: J1.CD (CARD_DETECT), J1.COM (COMMON), J1.WP (WRITE_PROTECT)
unnamed: J1.1 (CD/DAT3), J2.1 (CD/DAT3)
unnamed: J1.5 (CLK), J2.5 (CLK)
unnamed: J1.2 (CMD), J2.2 (CMD)
unnamed: J1.11 (D0+), J2.11 (D0+)
unnamed: J1.12 (D0-), J2.12 (D0-)
unnamed: J1.16 (D1+), J2.16 (D1+)
unnamed: J1.15 (D1-), J2.15 (D1-)
unnamed: J1.7 (DAT0), J2.7 (DAT0)
unnamed: J1.8 (DAT1), J2.8 (DAT1)
unnamed: J1.9 (DAT2), J2.9 (DAT2)
unnamed: J1.17 (Name), J2.17 (Name)
unnamed: J1.SH (SHIELD), J3.SH (SHIELD), J4.SH (SHIELD)
unnamed: J1.14 (VDD2), J2.14 (VDD2)
unnamed: J1.4 (VDD), J2.4 (VDD)
unnamed: J1.3 (VSS1), J2.3 (VSS1), J2.10 (VSS3)
unnamed: J1.6 (VSS2), J2.6 (VSS2)
unnamed: J1.13 (VSS4), J2.13 (VSS4)
unnamed: J3.CD (CARD_DETECT), J4.CD (CARD_DETECT)
unnamed: J3.1 (CD/DAT3), J4.1 (CD/DAT3)
unnamed: J3.5 (CLK), J4.5 (CLK)
unnamed: J3.2 (CMD), J4.2 (CMD)
unnamed: J3.COM (COMMON), J4.COM (COMMON)
unnamed: J3.11 (D0+), J4.11 (D0+)
unnamed: J3.12 (D0-), J4.12 (D0-)
unnamed: J3.16 (D1+), J4.16 (D1+)
unnamed: J3.15 (D1-), J4.15 (D1-)
unnamed: J3.7 (DAT0), J4.7 (DAT0)
unnamed: J3.8 (DAT1), J4.8 (DAT1)
unnamed: J3.9 (DAT2), J4.9 (DAT2)
unnamed: J3.17 (Name), J4.17 (Name)
unnamed: J3.14 (VDD2), J4.14 (VDD2)
unnamed: J3.4 (VDD), J4.4 (VDD)
unnamed: J3.3 (VSS1), J4.3 (VSS1)
unnamed: J3.6 (VSS2), J4.6 (VSS2)
unnamed: J3.13 (VSS4), J4.13 (VSS4)
unnamed: J3.WP (WRITE_PROTECT), J4.WP (WRITE_PROTECT)

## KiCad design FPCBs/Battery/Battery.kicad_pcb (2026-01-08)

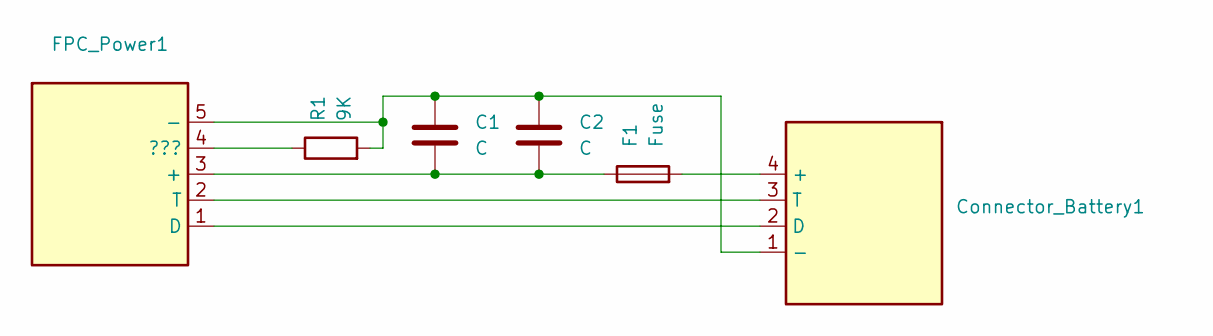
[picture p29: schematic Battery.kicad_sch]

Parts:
C1, C2: C; R_2x1mm
Connector_Battery1: Connector_Battery
F1: Fuse; R_2x1mm
FPC_Power1: FPC_Power
R1: 9K; R_2x1mm

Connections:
unnamed: Connector_Battery1.4 (+), F1.2
unnamed: C1.1, C2.1, Connector_Battery1.1 (-), FPC_Power1.5 (-), R1.2
unnamed: Connector_Battery1.2 (D), FPC_Power1.1 (D)
unnamed: Connector_Battery1.3 (T), FPC_Power1.2 (T)
unnamed: C1.2, C2.2, F1.1, FPC_Power1.3 (+)
unnamed: FPC_Power1.4 (???), R1.1

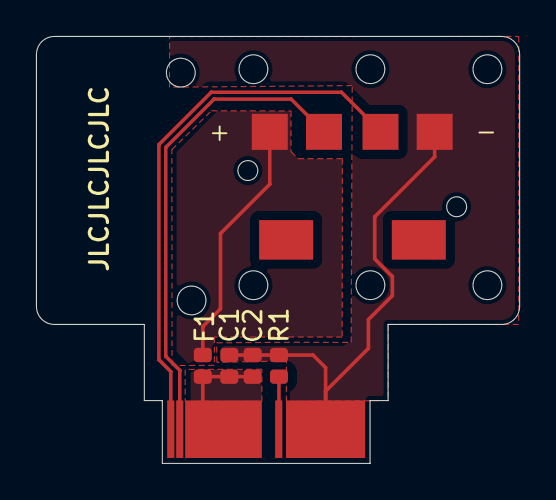
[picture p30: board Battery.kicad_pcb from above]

Board: 2 copper layers, 26.8 x 23.7 mm, 6 parts (0 on the bottom side), 6 nets.

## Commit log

2025-06-19 Add battery fpcb
    [Battery.kicad_pcb, Battery.kicad_sch]
2025-06-21 Battery fpcb
    [Battery-B_Cu.gbl, Battery-B_Mask.gbs, Battery-B_Paste.gbp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]
2025-06-21 Add more boards
    [2nd_shutter.kicad_pcb, 2nd_shutter.kicad_sch, Left.kicad_pcb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]
2025-06-23 Add driving modes switch
    [Left.kicad_pcb, Left.kicad_sch]
2025-06-29 Export buttons and dials
    [Base Plate - Bottom.dxf, Clickers.step, Dials.step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]
2025-06-29 Connect the clickers
    [Clickers-connected.step]
2025-07-02 Finish schematic
    [Right.kicad_sch]
2025-07-05 Add footprints
    [Right.kicad_pcb, Right.kicad_sch]
2025-07-09 Extend fpc size
    [Right.kicad_pcb, Right.kicad_sch]
2025-07-09 Add connector
    [Left.kicad_pcb, Left.kicad_sch]
2025-07-13 Adjust the 35 pins connector
    [Right.kicad_pcb]
2025-07-27 Update the back pcb
    [Back.kicad_pcb, Back.kicad_sch, Right.kicad_pcb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]
2025-07-27 Fix 4 pins connector
    [2nd_shutter.kicad_pcb, 2nd_shutter.kicad_sch, Right.kicad_pcb]
2025-07-27 Update to kicad 9
    [Left.kicad_pcb, Left.kicad_sch, Right.kicad_sch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]
2025-08-04 Add sd card
    [Back.kicad_pcb, Back.kicad_sch, SDCards.kicad_pcb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]
2025-08-06 Add pad mask
    [Battery.kicad_pcb, Battery.kicad_sch, SDCards.kicad_pcb]
2025-08-07 Add masks to the battery pcb
    [Battery-B_Cu.gbl, Battery-B_Mask.gbs, Battery-B_Paste.gbp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]
2025-08-07 Add EVF extender FPCB
    [Battery.kicad_pcb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]
2025-08-07 Add curved tracks
    [EVF_extender.kicad_pcb]
2025-08-08 Add stiffeners
    [EVF_extender.kicad_pcb]
2025-08-08 Fixes on the left side FPC
    [Left-B_Cu.gbl, Left-B_Mask.gbs, Left-B_Paste.gbp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]
2025-08-09 Move leds to Right board
    [EVF_extender-B_Cu.gbl, EVF_extender-B_Mask.gbs, EVF_extender-B_Paste.gbp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]
2025-08-09 Add extra switch for on/off
    [Right-B_Cu.gbl, Right-B_Mask.gbs, Right-B_Paste.gbp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]
2025-08-10 Fixes for the back pcb
    [Back-B_Cu.gbl, Back-B_Mask.gbs, Back-B_Paste.gbp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]
2025-08-11 Update USBC
    [USBC.kicad_sch, USBC_90deg.kicad_pcb]
2025-08-11 Fix the usbc extender
    [Battery-B_Cu.gbl, Battery-B_Mask.gbs, Battery-B_Paste.gbp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]
2025-08-11 Rename folder
    [Back-B_Cu.gbl, Back-B_Mask.gbs, Back-B_Paste.gbp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]
2025-08-12 Add copper tot he back side
    [EVF_extender-B_Cu.gbl, EVF_extender-B_Mask.gbs, EVF_extender-B_Paste.gbp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]
2025-08-12 Add back copper
    [Back-B_Cu.gbl, Back-B_Mask.gbs, Back-B_Paste.gbp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]
2025-08-13 Add gyro holder 3D model
    [Gyro.step, Mask.step]
2025-08-13 Decrease the second row pads width in the fpc connector 35pins
    [Back-B_Cu.gbl, Back-B_Mask.gbs, Back-B_Paste.gbp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]
2025-08-28 Add Canon shutter footprint
    [Left.kicad_sch, Right.kicad_pcb, Right.kicad_sch]
2025-09-07 Fix the buttons pins
    [Back.kicad_pcb, Back.kicad_sch, Right.kicad_pcb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]
2025-09-08 Fix back wheel footprint
    [Back.kicad_pcb]
2025-09-09 Fixes to Back board
    [Back-B_Cu.gbl, Back-B_Mask.gbs, Back-B_Paste.gbp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]
2025-09-10 Fixes to back pcb
    [Back.kicad_pcb]
2025-09-10 Move fpc to left
    [Right.kicad_pcb]
2025-09-11 Fixes to the right pcb
    [Right.kicad_pcb]
2025-09-11 Add serpentines
    [Right.kicad_pcb]
2025-09-11 Add through holes for on off switch
    [Right.kicad_pcb, Right.kicad_sch]
2025-09-12 Fix small battery footprint
    [Right.kicad_pcb]
2025-09-13 Fixes on the shutter
    [Right.kicad_pcb, Right.kicad_sch]
2025-09-13 Move evf sensor to left
    [Back.kicad_pcb]
2025-09-14 Second shutter FPC
    [Right.kicad_pcb, Right.kicad_sch]
2025-09-14 Fix back wheel
    [Back.kicad_pcb, Back.kicad_sch]
2025-09-15 Add 1st dial connector
    [Right.kicad_pcb, Right.kicad_sch]
2025-09-15 Generate Gerbers
    [Back-B_Cu.gbl, Back-B_Mask.gbs, Back-B_Paste.gbp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]
2025-10-27 Update image
    [Right.kicad_sch]
2025-11-13 Rewire one side of the evf connector to the back side
    Add Lumix logo
    [EVF_extender.kicad_pcb]
2025-12-02 Add engravings
    [Right.kicad_pcb, Right.kicad_sch, TopPlate.dxf]
2025-12-18 Correct evf distance
    [Back.kicad_pcb, EVF_extender.kicad_pcb, EVF_extender.kicad_sch]
2025-12-18 Fix stiffeners
    [EVF_extender.kicad_pcb]
2026-01-07 Add second shutter
    [Right.kicad_pcb, Right.kicad_sch]
2026-01-07 Update the licence with CERN-OHL-P-2.0
    [Back.kicad_sch]
2026-01-08 Add EVF optocoupler
    [Back.kicad_pcb, Back.kicad_sch]
2026-01-08 Fix battery fpc size
    [Battery.kicad_pcb]
2026-01-08 Fix left fpcb
    [Left.kicad_pcb, Left.kicad_sch, Right.kicad_pcb]
2026-01-09 sd card
    [SDCards.kicad_pcb, SDCards.kicad_sch]
2026-01-11 Add second power button
    [EVF_extender.kicad_pcb, Right.kicad_pcb, Right.kicad_sch]
2026-01-11 Fix positions on back fpcb
    [Back.kicad_pcb, Right.kicad_pcb]
2026-01-13 Improve the back fpcb
    [Back.kicad_pcb, Back.kicad_sch]
2026-01-17 Add front lever flex cable
    [Back.kicad_pcb, Back.kicad_sch]
2026-01-20 Fix switch detectors footprints
    [Back.kicad_pcb]
2026-01-23 Adjustments for evf and right fpcb
    [EVF_extender.kicad_pcb, Right.kicad_pcb, Right.kicad_sch]
2026-01-24 Fix sd card
    [SDCards.kicad_pcb, SDCards.kicad_sch]
2026-01-25 Fix spacings and pads
    [SDCards.kicad_pcb, SDCards.kicad_sch]
2026-01-26 Fix connectors
    [Back.kicad_pcb, Back.kicad_sch, Right.kicad_pcb]
2026-01-26 Add holes to switch detectors
    [Back.kicad_pcb]
2026-01-26 Fix masks
    [Back.kicad_pcb]
2026-01-27 Enlarge pcb to allow bending
    [Back.kicad_pcb]
2026-02-24 Export new Gerbers and CADs
2026-02-25 Arrange buttons differently to meet minimum size requirement by cnc
